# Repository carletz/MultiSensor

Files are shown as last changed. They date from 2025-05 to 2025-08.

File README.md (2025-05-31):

# ESPHome 🧠 MultiSensor Board

This repository contains the full hardware and firmware implementation of a smart multisensor platform powered by ESP32-S3, designed for home and building automation environments.
The purpose of this sensor is to install it on the room ceiling and detect the data by transmitting it to MQTT server, and use the IR led for communication with equipment such as televisions, air conditioners and more.
The idea was to have a sensor that could be freed from the difficulty of running power cables and data cables. The use of ethernet cables and POE connection facilitates the entire distribution and guarantees the correct connection in case of Wi-Fi difficulties.
It is still possible to connect it with a USB-C port and a wireless network but it was not designed for that.

---
## 🔧 Features

- **ESP32-S3 microcontroller** with USB-C and GPIO breakout
- **Power-over-Ethernet (PoE)** with isolated DC-DC conversion (via TPS2376 + F0505S module)
- **W5500 Ethernet controller** with magnetics and RJ45 connector
- **Sensor suite includes:**
  - BME280 for temperature, humidity, pressure (I²C)
  - BH1750 light sensor (I²C)
  - SCD41 for CO₂, humidity, temperature (I²C)
  - HLK-LD2410C-P mmWave presence sensor (UART)
  - SFH4546 IR emitters
- **GPIOs for external modules**
- **3.3V and 5V power rails with LDO and flyback conversion**
- **Status LEDs and reset circuitry**
- **Designed in EasyEDA (3 schematic sheets)**

## 🖼️ Board Preview

Below is a 3D render of the custom MultiSensor PCB, including:
- ESP32-S3
- W5500 Ethernet with PoE
- Sensors (BME280, BH1750, SCD41, HLK-LD2410C-P)
- USB-C and GPIO headers

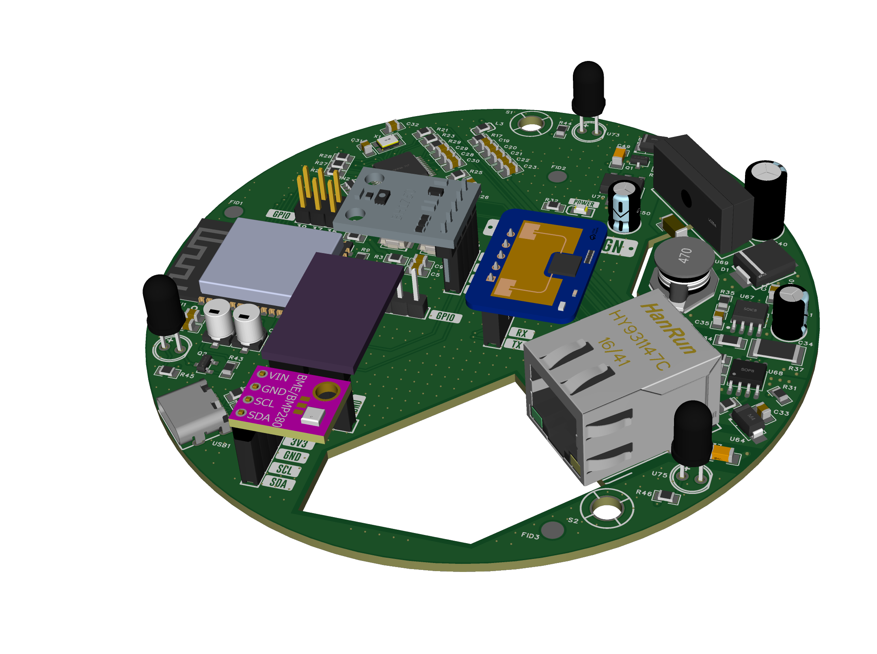
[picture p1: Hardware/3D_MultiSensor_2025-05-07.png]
3D Render of the MultiSensor Board


---
## 🎥 Construction Video

Watch the video (https://www.youtube.com/watch?v=1dLpgVjPY0A)

---
## 📡 Firmware

The board runs on **ESPHome**, fully integrated with:
- MQTT publishing (structured per sensor category)
- Web interface on Ethernet
- OTA update
- Diagnostics, presence, and environmental data

See Sensor.yaml for the complete ESPHome configuration.
Please consider that in this case, for the publication of the topics, the file is set having different floors and different rooms, the names are just an example.

## 📂 Folder Structure

- `Software` → ESPHome configuration
- `Hardware` → Complete hardware schematic (3 pages) and PCB design
- `3D design` → **Under developement** 3D model for 3D printed case
- `LICENSE` → MIT License

---
## 🧰 Getting Started

1. Flash `Sensor.yaml` using ESPHome Dashboard or CLI.
2. Connect the board to a PoE-enabled Ethernet switch or inject 5V via USB-C.
3. Open the web interface at the IP assigned via DHCP.
4. Integrate with Home Assistant or any MQTT broker at `192.168.1.XXX`.

---
## ⚠️ Disclaimer

This project is provided **for educational purposes only**.

The author(s) of this repository do **not take any responsibility** for:
- Incorrect use of the design or schematics
- Damage to equipment, persons, or property
- Installation in unsafe or non-compliant environments

Any implementation of this project in real-world systems should be done **under the responsibility of a qualified professional**, and in compliance with local regulations and safety standards.

By using this material, you acknowledge that it is offered **as-is, without warranty of any kind**, and you agree to use it **at your own risk**.

## 🌍 Language Note

Please note that some of the documentation and schematic files included in this project are written in **Italian**.

This is because the project was originally developed and documented for local use. I plan to translate all materials into **English** as time permits, to make the project more accessible to the international community.

If you need help understanding any specific part, feel free to open an issue or contact me — I'll be happy to help.

Grazie for your patience! 🇮🇹🙂

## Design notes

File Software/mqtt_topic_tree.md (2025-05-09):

# MQTT Topic Tree for ESPHome - Piano4 / Studio

This document outlines all MQTT topics published by the ESPHome node `sensore_piano4_studio`, located in the area `Piano4`, stanza `Studio`.

## 📡 MQTT Topics

```
Piano4/Studio/
├── Ambiente/
│   ├── Pressione
│   ├── Temperatura
│   └── Umidita
├── Aria/
│   ├── CO2
│   ├── Temperatura
│   └── Umidita
├── Diagnostica/
│   ├── Bluetooth
│   ├── Engineering Mode
│   ├── ESP_Reboot
│   ├── Esp temperatura
│   ├── IP
│   ├── DNS
│   ├── MAC
│   ├── Query
│   ├── Reboot
│   ├── Reset
│   ├── Uptime
│   └── Versione
├── IR/
│   └── Accendi_TV
├── Luce/
│   └── Lux
├── Presenza/
│   ├── Detection distance
│   ├── Light
│   ├── Move energy
│   ├── Moving distance
│   ├── Moving_target
│   ├── Out_pin
│   ├── Presence
│   ├── Still energy
│   ├── Still distance
│   ├── Still_target
│   ├── G0/
│   │   ├── Move_Energy
│   │   ├── Still_Energy
│   │   ├── Move Threshold
│   │   └── Still Threshold
│   ├── G1/ ... G8/
│   │   (identico a G0 per ogni gruppo)
│   └── Parametri/
│       ├── Baud Rate
│       ├── Distance Resolution
│       ├── G0 → G8/
│       │   ├── Move Threshold
│       │   └── Still Threshold
│       ├── Light Function
│       ├── Light Threshold
│       ├── Max Move Distance
│       ├── Max Still Distance
│       ├── Out Pin Level
│       └── Timeout
```

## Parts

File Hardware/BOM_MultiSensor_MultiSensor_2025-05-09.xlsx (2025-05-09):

No. | Quantity | Comment | Designator | Footprint | Value | Manufacturer Part | Manufacturer | Supplier Part | Supplier | LCSC Stock | LCSC Price | Primary Category | Secondary Category | Pin Count | JLCPCB Stock | JLCPCB Price | 3D Model Title | Device | Name | Unique ID | Convert to PCB | Add into BOM | Symbol | Layer | Mounting Style
1 | 2 | TS-1088-AR02016 | ((BOOT)),((RESET)) | SW-SMD_L3.9-W3.0-P4.45 |  | TS-1088-AR02016 | XUNPU(讯普) | C720477 | LCSC |  |  | Switches | Tactile Switches | 2 |  |  | SW-SMD_L3.9-W2.9-H2.0-LS4.8 | TS-1088-AR02016 | TS-1088-AR02016 | gge95,gge98 |  | yes |  | T | Brick nogging
2 | 1 | XL-2012SURC | ((POWER)) | LED0805-R-RD |  | XL-2012SURC | XINGLIGHT(成兴光) | C965812 | LCSC |  |  | Optoelectronics | LED Indication - Discrete | 2 |  |  | LED0805-RD | XL-2012SURC | XL-2012SURC | gge156_10 |  | yes |  | T
3 | 2 | 10uF | C1,C11 | C0805 | 10uF | CL21A106KOQNNNE | SAMSUNG(三星) | C1713 | LCSC |  |  | Capacitors | Multilayer Ceramic Capacitors MLCC - SMD/SMT | 2 |  |  | C0805_L2.0-W1.3-H1.3 | CL21A106KOQNNNE | 10uF | gge199,gge200 |  | yes |  | T
4 | 2 | 10uF | C2,C3 | CAP-SMD_BD4.0-L4.3-W4.3-LS5.1-FD | 10uF | VE-100M1ATR-0405 | lelon(立隆) | C249449 | LCSC |  |  | Capacitors | Aluminum Electrolytic Capacitors - SMD | 2 |  |  | CAP-SMD_BD4.0-L4.3-W4.3-LS5.1-FD | VE-100M1ATR-0405 | 10uF | gge137_1,gge138_1 |  | yes |  | T
5 | 10 | 100nF | C4,C6,C7,C12,C13,C14,C15,C21,C26,C32 | C0805 | 100nF | CL21B104KCFNNNE | SAMSUNG(三星) | C28233 | LCSC |  |  | Capacitors | Multilayer Ceramic Capacitors MLCC - SMD/SMT | 2 |  |  | C0805_L2.0-W1.3-H1.3 | CL21B104KCFNNNE | 100nF | gge211,gge212,gge213,gge213_1,gge214,gge214_1,gge215,gge216,gge217,gge218 |  | yes |  | T
6 | 1 | 1uF | C5 | C0805 | 1uF | HHV0805R7105K101NSLJ | Chinocera(华瓷) | C22367837 | LCSC |  |  | Capacitors | Multilayer Ceramic Capacitors MLCC - SMD/SMT | 2 |  |  | C0805_L2.0-W1.3-H1.3 | HHV0805R7105K101NSLJ | 1uF | gge251 |  | yes |  | T
7 | 1 | 10uF | C8 | C1206 | 10uF | CL31A106KBHNNNE | SAMSUNG(三星) | C13585 | LCSC |  |  | Capacitors | Multilayer Ceramic Capacitors MLCC - SMD/SMT | 2 |  |  | C1206_L3.2-W1.6-H1.3 | CL31A106KBHNNNE | 10uF | gge48_1 |  | yes |  | T
8 | 1 | 10uF | C9 | CAP-TH_BD5.0-P2.00-D0.8-FD | 10uF | GR106M050D11RR0VK2FP0 | CX(承兴) | C78759 | LCSC |  |  | Capacitors | Aluminum Electrolytic Capacitors - Leaded | 2 |  |  | CAP-TH_D5.0×H7.0×P2.0 | GR106M050D11RR0VK2FP0 | 10uF | gge120_1 |  | yes |  | T
9 | 2 | 6.8nF | C10,C18 | C0805 | 6.8nF | 0805B682K500NT | FH(风华) | C1755 | LCSC |  |  | Capacitors | Multilayer Ceramic Capacitors MLCC - SMD/SMT | 2 |  |  | C0805_L2.0-W1.3-H1.3 | 0805B682K500NT | 6.8nF | gge233,gge234 |  | yes |  | T
10 | 2 | 10nF | C16,C20 | C0805 | 10nF | FV21X103K102ECG | PSA(信昌电陶) | C565682 | LCSC |  |  | Capacitors | Multilayer Ceramic Capacitors MLCC - SMD/SMT | 2 |  |  | C0805_L2.0-W1.3-H1.3 | FV21X103K102ECG | 10nF | gge206,gge207 |  | yes |  | T
11 | 1 | 22nF | C17 | C0805 | 22nF | CC0805KRX7R9BB223 | YAGEO(国巨) | C107147 | LCSC |  |  | Capacitors | Multilayer Ceramic Capacitors MLCC - SMD/SMT | 2 |  |  | C0805_L2.0-W1.3-H1.3 | CC0805KRX7R9BB223 | 22nF | gge255 |  | yes |  | T
12 | 1 | 4.7uF | C19 | C0805 | 4.7uF | CC0805KKX7R5BB475 | YAGEO(国巨) | C520073 | LCSC |  |  | Capacitors | Multilayer Ceramic Capacitors MLCC - SMD/SMT | 2 |  |  | C0805_L2.0-W1.3-H1.3 | CC0805KKX7R5BB475 | 4.7uF | gge228 |  | yes |  | T
13 | 1 | 1nF | C22 | C1206 | 1nF | HHV1206R7102K202NSLJ | Chinocera | C5186823 | LCSC |  |  | Capacitors | Multilayer Ceramic Capacitors MLCC - SMD/SMT | 2 |  |  | C1206_L3.2-W1.6-H1.3 | CC1206KKX7RDBB102 | 1nF | gge275 |  | yes |  | T
14 | 2 | 20pF | C23,C24 | C0805 | 20pF | TCC0805COG200J500BT | CCTC(三环) | C309037 | LCSC |  |  | Capacitors | Multilayer Ceramic Capacitors MLCC - SMD/SMT | 2 |  |  | C0805_L2.0-W1.3-H1.3 | TCC0805COG200J500BT | 20pF | gge229,gge230 |  | yes |  | T
15 | 2 | 1nF | C25,C30 | C1808 | 1nF | 1808B102K302NT | FH(风华) | C967608 | LCSC |  |  | Capacitors | Multilayer Ceramic Capacitors MLCC - SMD/SMT | 2 |  |  | C1808_L4.5-W2.0-H2.0 | 1808B102K302NT | 1nF | gge307,gge308 |  | yes |  | T
16 | 1 | 15uF | C27 | CAP-TH_BD5.0-P2.00-D0.8-FD | 15uF | LKMB1102A150MF | Ymin(永铭) | C443117 | LCSC |  |  | Capacitors | Aluminum Electrolytic Capacitors - Leaded | 2 |  |  | CAP-TH_D5.0×H7.0×P2.0 | LKMB1102A150MF | 15uF | gge269 |  | yes |  | T
17 | 1 | 12pF | C28 | C0805 | 12pF | 0805CG120J500NT | FH(风华) | C1792 | LCSC |  |  | Capacitors | Multilayer Ceramic Capacitors MLCC - SMD/SMT | 2 |  |  | C0805_L2.0-W1.3-H1.3 | 0805CG120J500NT_C1792 | 12pF | gge277 |  | yes |  | T
18 | 1 | 470uF | C29 | CAP-TH_BD6.3-P2.50-D1.0-FD | 470uF | NXB10V470M6.3*11 LO | SAMYOUNG(韩国三莹) | C371106 | LCSC |  |  | Capacitors | Aluminum Electrolytic Capacitors - Leaded | 2 |  |  | CAP-TH_BD6.3-P2.50-D1.0-FD | NXB10V470M6.3*11 LO | 470uF | gge280 |  | yes |  | T
19 | 1 | 22uF | C31 | C0805 | 22uF | CL21A226MQQNNNE | SAMSUNG(三星) | C5674 | LCSC |  |  | Capacitors | Multilayer Ceramic Capacitors MLCC - SMD/SMT | 2 |  |  | C0805_L2.0-W1.3-H1.3 | CL21A226MQQNNNE | 22uF | gge284 |  | yes |  | T
20 | 1 | SS510C | D1 | SMC_L7.1-W6.2-LS8.1-R-RD |  | SS510C | FUXINSEMI | C908242 | LCSC |  |  | Diodes | Schottky Diodes | 2 |  |  | SMC_L7.1-W6.2-LS8.1-RD1 | SS510C | SS510C | gge272 |  | yes |  | T
21 | 1 | SMBJ6.0A | D2 | SMB_L4.6-W3.6-LS5.3-RD |  | SMBJ6.0A | Littelfuse(美国力特) | C83270 | LCSC |  |  | Circuit Protection | ESD and Surge Protection (TVS/ESD) | 2 |  |  | SMB_L4.6-W3.6-LS5.3-R-RD | SMBJ6.0A_C83270 | SMBJ6.0A | gge285 |  | yes |  | T
22 | 1 | 1N5819 | D3 | SMA_L4.4-W2.6-LS5.0-RD |  | 1N5819 | KEXIN(科信) | C437199 | LCSC |  |  | Diodes | Schottky Diodes | 2 |  |  | SMA_L4.4-W2.6-LS5.0-RD | 1N5819_C437199 | 1N5819 | gge261 |  | yes |  | T
23 | 3 | Fiducial | FID1,FID2,FID3 | Fiducial10-30 |  |  | N/A |  |  |  |  |  |  | 1 |  |  |  | Fiducial | Fiducial | gge299,gge300,gge301 |  | yes |  | T
24 | 1 | HDR-M_2.54_2x3 | H1 | HDR-TH_6P-P2.54-V-R2-C3-S2.54_A2541WV-2X3P |  |  |  |  |  |  |  | Connectors | Pin Headers | 6 |  |  | HDR2.54-M-LI-2x3P | HDR-M_2.54_2x3 |  | gge260 |  | yes |  | T
25 | 4 | 2.54-1*4P母 | H2,H6,H7,H8 | HDR-TH_4P-P2.54-V-F |  | 2.54-1*4P母 | BOOMELE(博穆精密) | C2718488 | LCSC |  |  | Connectors | Female Headers | 4 |  |  | HDR-TH_4P-P2.54-V-F-2,HDR-TH_4P-P2.54-V-F-3_WJ254 | 2.54-1*4P母 | 2.54-1*4P母 | gge302,gge303,gge303_1,gge304 |  | yes |  | T
26 | 1 | 2.54-1*5P母 | H5 | HDR-TH_5P-P2.54-V-F |  | 2.54-1*5P母 | BOOMELE(博穆精密) | C50950 | LCSC |  |  | Connectors | Female Headers | 5 |  |  | HDR-TH_5P-P2.54-V-F-B | HDR-F_2.54_1x5P |  | gge305 |  | yes |  | T
27 | 1 | HCB2012KF-121T50 | L1 | L0805 |  | HCB2012KF-121T50 | TAI-TECH(台庆) | C304323 | LCSC |  |  | Filters | Ferrite Beads | 2 |  |  | R0805_L2.0-W1.3-H0.6 | HCB2012KF-121T50 | HCB2012KF-121T50 | gge241 |  | yes |  | T
28 | 1 | 33uH | L2 | IND-SMD_L12.9-W9.8 | 33uH | SMSD0804-330MT | SXN(顺翔诺) | C286357 | LCSC |  |  | Inductors, Coils, Chokes | Power Inductors | 2 |  |  | IND-SMD_L12.9-W9.8-H5.2 | SMSD0804-330MT | 33uH | gge276 |  | yes |  | T
29 | 1 | WPM2015-3/TR | Q1 | SOT-23-3_L2.9-W1.3-P1.90-LS2.4-BR |  | WPM2015-3/TR | KUU | C6562215 | LCSC |  |  | Transistors/Thyristors | MOSFETs | 3 |  |  | SOT-23-3P_L2.9-W1.3-H1.0-LS2.4-P0.95 | WPM2015-3/TR_C6562215 | WPM2015-3/TR | gge262 |  | yes |  | T
30 | 1 | BSS138BK | Q2 | SOT-23-3_L2.9-W1.3-P1.90-LS2.4-BR |  | BSS138BK | ElecSuper(静芯微) | C5224267 | LCSC |  |  | Transistors/Thyristors | MOSFETs | 3 |  |  | SOT-23-3P_L2.9-W1.3-H1.0-LS2.4-P0.95 | BSS138BK | BSS138BK | gge292 |  | yes |  | T
31 | 3 | 10Ω | R1,R2,R13 | R0805_NEW | 10Ω | 0805W8F100JT5E | UNI-ROYAL(厚声) | C17415 | LCSC |  |  | Resistors | Chip Resistor - Surface Mount | 2 |  |  | R0805_L2.0-W1.3-H0.6 | 0805W8F100JT5E | 10Ω | gge239,gge249,gge250 |  | yes |  | T
32 | 13 | 10kΩ | R3,R4,R5,R6,R7,R8,R9,R11,R21,R22,R23,R24,R33 | R0805 | 10kΩ | RC0805FR-7W10KL | YAGEO(国巨) | C17414 | LCSC |  |  | Resistors | Chip Resistor - Surface Mount | 2 |  |  | R0805_L2.0-W1.3-H0.6 | RC0805FR-7W10KL | 10kΩ | gge202,gge202_1,gge203,gge204,gge205,gge220,gge221,gge222,gge223,gge224,gge224_1,gge225,gge226 |  | yes |  | T
33 | 2 | 2kΩ | R10,R37 | R0805 | 2kΩ | 0805W8J0202T5E | UNI-ROYAL(厚声) | C1359 | LCSC |  |  | Resistors | Chip Resistor - Surface Mount | 2 |  |  | R0805_L2.0-W1.3-H0.6 | 0805W8J0202T5E | 2kΩ | gge253_1,gge253_2 |  | yes |  | T
34 | 1 | 0Ω | R12 | R0805 | 0Ω | 0805W8F0000T5E | UNI-ROYAL(厚声) | C17477 | LCSC |  |  | Resistors | Chip Resistor - Surface Mount | 2 |  |  | R0805_L2.0-W1.3-H0.6 | 0805W8F0000T5E_C17477 | 0Ω | gge240 |  | yes |  | T
35 | 2 | 49.9Ω | R14,R15 | R0805 | 49.9Ω | 0805W8F499JT5E | UNI-ROYAL(厚声) | C17720 | LCSC |  |  | Resistors | Chip Resistor - Surface Mount | 2 |  |  | R0805_L2.0-W1.3-H0.6 | 0805W8F499JT5E | 49.9Ω | gge237,gge238 |  | yes |  | T
36 | 2 | 82Ω | R16,R17 | R0805 | 82Ω | RC0805FR-0782RL | YAGEO(国巨) | C141699 | LCSC |  |  | Resistors | Chip Resistor - Surface Mount | 2 |  |  | R0805_L2.0-W1.3-H0.6 | RC0805FR-0782RL | 82Ω | gge231,gge232 |  | yes |  | T
37 | 2 | 510Ω | R18,R19 | R0805 | 510Ω | FRC0805J511 TS | FOJAN(富捷) | C2907333 | LCSC |  |  | Resistors | Chip Resistor - Surface Mount | 2 |  |  | R0805_L2.0-W1.3-H0.6 | FRC0805J511 TS | 510Ω | gge235,gge236 |  | yes |  | T
38 | 1 | 12.4kΩ | R20 | R0805 | 12.4kΩ | 0805W8F1242T5E | UNI-ROYAL(厚声) | C30908 | LCSC |  |  | Resistors | Chip Resistor - Surface Mount | 2 |  |  | R0805_L2.0-W1.3-H0.6 | 0805W8F1242T5E | 12.4kΩ | gge243 |  | yes |  | T
39 | 1 | 4.7Ω | R25 | R0805 | 4.7Ω | FRC0805F4R70TS | FOJAN(富捷) | C2907327 | LCSC |  |  | Resistors | Chip Resistor - Surface Mount | 2 |  |  | R0805_L2.0-W1.3-H0.6 | FRC0805F4R70TS | 4.7Ω | gge271 |  | yes |  | T
40 | 1 | 4.7kΩ | R26 | R2512 | 4.7kΩ | FRC2512J472 TS | FOJAN | C2907583 | LCSC |  |  | Resistors | Chip Resistor - Surface Mount | 2 |  |  | R2512_L6.3-W3.2-H0.6 | 25121WF4701T4E | 4.7kΩ | gge274 |  | yes |  | T
41 | 1 | 56.2kΩ | R27 | R0805 | 56.2kΩ | FRC0805F5622TS | FOJAN(富捷) | C2933471 | LCSC |  |  | Resistors | Chip Resistor - Surface Mount | 2 |  |  | R0805_L2.0-W1.3-H0.6 | FRC0805F5622TS | 56.2kΩ | gge278 |  | yes |  | T
42 | 1 | 180kΩ | R28 | R0805 | 180kΩ | FRC0805F1803TS | FOJAN(富捷) | C2907230 | LCSC |  |  | Resistors | Chip Resistor - Surface Mount | 2 |  |  | R0805_L2.0-W1.3-H0.6 | FRC0805F1271TS | 180kΩ | gge266 |  | yes |  | T
43 | 1 | 30mΩ | R29 | R1206 | 30mΩ | PA1206FRF470R03L | YAGEO(国巨) | C728293 | LCSC |  |  | Resistors | Chip Resistor - Surface Mount | 2 |  |  | R1206_L3.2-W1.6-H0.6 | PA1206FRF470R03L | 30mΩ | gge270 |  | yes |  | T
44 | 1 | 130kΩ | R30 | R0805 | 130kΩ | FRC0805F1303TS | FOJAN | C2933305 | LCSC |  |  | Resistors | Chip Resistor - Surface Mount | 2 |  |  | R0805_L2.0-W1.3-H0.6 | RC0805FR-7W10KL | 130kΩ | gge202_2 |  | yes |  | T
45 | 1 | 10.5kΩ | R31 | R0805 | 10.5kΩ | FRC0805F1052TS | FOJAN | C2960821 | LCSC |  |  | Resistors | Chip Resistor - Surface Mount | 2 |  |  | R0805_L2.0-W1.3-H0.6 | FRC0805F5622TS | 10.5kΩ | gge279 |  | yes |  | T
46 | 1 | 4.42kΩ | R32 | R0805 | 4.42kΩ | FRC0805F4421TS | FOJAN(富捷) | C2960870 | LCSC |  |  | Resistors | Chip Resistor - Surface Mount | 2 |  |  | R0805_L2.0-W1.3-H0.6 | FRC0805F6652TS | 4.42kΩ | gge267 |  | yes |  | T
47 | 3 | 24Ω | R34,R35,R36 | R0805 | 24Ω | 0805W8F240JT5E | UNI-ROYAL(厚声) | C17576 | LCSC |  |  | Resistors | Chip Resistor - Surface Mount | 2 |  |  | R0805_L2.0-W1.3-H0.6 | 0805W8F240JT5E | 24Ω | gge293,gge294,gge295 |  | yes |  | T
48 | 1 | HY931147C | RJ1 | RJ45-TH_HY931147C |  | HY931147C | HANRUN(汉仁) | C91754 | LCSC |  |  | Connectors | Ethernet Connectors / Modular Connectors (RJ45 RJ11) | 16 |  |  | RJ45-TH_HY931147C | HY931147C | HY931147C | gge263 |  | yes |  | T | -
49 | 2 | 10kΩ | RN1,RN2 | RES-ARRAY-SMD_0603-8P-L3.2-W1.6-BL | 10kΩ | 4D03WGJ0103T5E | UNI-ROYAL(厚声) | C29718 | LCSC |  |  | Resistors | Resistor Networks, Arrays | 8 |  |  | R0603-8P_L3.2-W1.6-H0.6 | 4D03WGJ0103T5E | 10kΩ | gge208,gge210 |  | yes |  | T
50 | 1 | HLK-LD2410C-P | SM1 | SENSOR-TH_HLK-LD2410C-P |  | HLK-LD2410C-P | HI-LINK(海凌科) | C19723500 | LCSC |  |  | Sensors | Sensor Modules | 0 |  |  | SENSOR-TH_HLK-LD2410C-P | HLK-LD2410C-P | HLK-LD2410C-P | gge288 |  | yes |  | T
51 | 1 | 2.4GHz | U1 | WIRELM-SMD_ESP32-S3-WROOM-1 | 2.4GHz | ESP32-S3-WROOM-1-N8R2 | ESPRESSIF(乐鑫) | C2913204 | LCSC |  |  | IoT/Communication Modules | WiFi Modules | 49 |  |  | ESP32-S3-WROOM-1-N16R2 | ESP32-S3-WROOM-1-N8R2 | 2.4GHz | gge102 |  | yes |  | T
52 | 1 | BL1117-33CX | U2 | SOT-223-4_L6.5-W3.5-P2.30-LS7.0-BR |  | BL1117-33CX | BL(上海贝岭) | C5400 | LCSC |  |  | Power Management (PMIC) | Voltage Regulators - Linear, Low Drop Out (LDO) Regulators | 4 |  |  | SOT-223-4P_L6.5-W3.5-H1.6-LS7.0-P2.30 | BL1117-33CX | BL1117-33CX | gge46_1 |  | yes |  | T
53 | 1 | W5500 | U3 | LQFP-48_L7.0-W7.0-P0.50-LS9.0-BL |  | W5500 | WIZNET | C32843 | LCSC |  |  | Interface | Ethernet Controllers | 48 |  |  | LQFP-48_L7.0-W7.0-H1.4-LS9.0-P0.50 | W5500 | W5500 | gge86 |  | yes |  | T
54 | 1 | F0505S-2WR2 | U4 | PWRM-TH_FXXXXS-1WR2 |  | F0505S-2WR2 | DEXU(德旭电子) | C909777 | LCSC |  |  | Power Modules | Isolated Power Modules | 4 |  |  | PWRM-TH_FXXXXS-1WR2 | F0505S-2WR2 | F0505S-2WR2 | gge281 |  | yes |  | T
55 | 1 | 24.9kΩ | U5 | R0805 | 24.9kΩ | FRC0805F2492TS | FOJAN(富捷) | C2930185 | LCSC |  |  | Resistors | Chip Resistor - Surface Mount | 2 |  |  | R0805_L2.0-W1.3-H0.6 | FRC0805F2492TS | 24.9kΩ | gge265 |  | yes |  | T
56 | 1 | SMAJ58A | U6 | SMA_L4.3-W2.7-LS5.0-RD |  | SMAJ58A | GOODWORK(固得沃克) | C2980408 | LCSC |  |  | Circuit Protection | ESD and Surge Protection (TVS/ESD) | 2 |  |  | SMA_L4.3-W2.7-LS5.0-RD | SMAJ58A_C2980408 | SMAJ58A | gge264 |  | yes |  | T
57 | 1 | TPS2376DDAR-H | U7 | SO-8_L4.9-W3.9-P1.27-LS6.0-BL-EP |  | TPS2376DDAR-H | TI(德州仪器) | C544899 | LCSC |  |  | Power Management (PMIC) | Power Over Ethernet (PoE) Controllers | 9 |  |  | SO-8_L4.9-W3.9-H1.5-LS5.9-P1.27 | TPS2376DDAR-H | TPS2376DDAR-H | gge273 |  | yes |  | T
58 | 1 | TX4138 | U8 | SOIC-8_L4.9-W3.9-P1.27-LS6.0-BL-EP |  | TX4138 | XDS(芯鼎盛) | C329267 | LCSC |  |  | Power Management (PMIC) | DC-DC Converters | 9 |  |  | SOIC-8_L4.9-W3.9-H1.7-LS6.0-P1.27 | TX4138 | TX4138 | gge268 |  | yes |  | T
59 | 1 | BME280 | U9 | BME280 |  |  |  |  |  |  |  |  |  | 0 |  |  | Sensor BME280 | BME280 |  | gge286 |  | yes |  | T
60 | 3 | SFH 4546 | U11,U12,U13 | LED-TH_BD5.6-P2.54-FD |  | SFH 4546 | OSRAM(欧司朗) | C2900373 | LCSC |  |  | Optoelectronics | Infrared LED Emitters | 2 |  |  | LED-TH_BD5.6-P2.54-L5.6-H8.6-FD | SFH 4546 | SFH 4546 | gge289,gge290,gge291 |  | yes |  | T
61 | 1 | BH1750 | U14 | BH1750 |  |  |  |  |  |  |  |  |  | 0 |  |  | BH1750 | BH1750 |  | gge306 |  | yes |  | T
62 | 1 | SCD41 | U15 | SCD40/SCD41 MODULE |  |  |  |  |  |  |  | Sensores |  | 0 |  |  | scd40 v7 | SCD41 |  | gge297 |  | yes |  | T
63 | 1 | TYPE-C 16PIN 2MD(073) | USB1 | USB-C-SMD_TYPE-C-6PIN-2MD-073 |  | TYPE-C 16PIN 2MD(073) | SHOU HAN(首韩) | C2765186 | LCSC |  |  | Connectors | USB Connectors | 16 |  |  | USB-C-SMD_TYPE-C-6PIN-2MD-073 | TYPE-C 16PIN 2MD(073) | TYPE-C 16PIN 2MD(073) | gge130_2 |  | yes |  | T | Horizontal attachment
64 | 1 | 25MHz | X1 | CRYSTAL-SMD_4P-L3.2-W2.5-BL | 25MHz | X322525MOB4SI | YXC(扬兴晶振) | C9006 | LCSC |  |  | Crystals, Oscillators, Resonators | Crystals | 4 |  |  | OSC-SMD_4P-L3.2-W2.5-H1.0 COPY | X322525MOB4SI | 25MHz | gge131_1 |  | yes |  | T

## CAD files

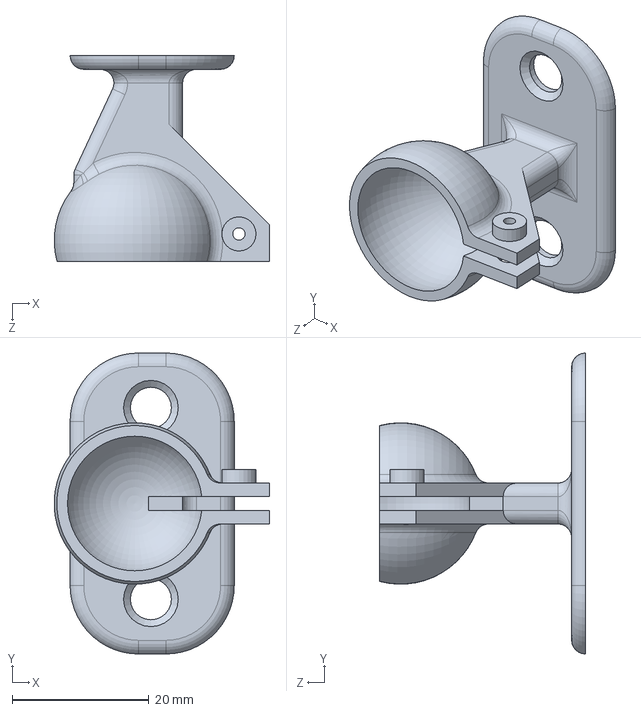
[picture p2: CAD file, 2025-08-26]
3D Design/Wall attach/PIEDE APPOGGIO.SLDPRT
31.5 x 44.0 x 30.1 mm

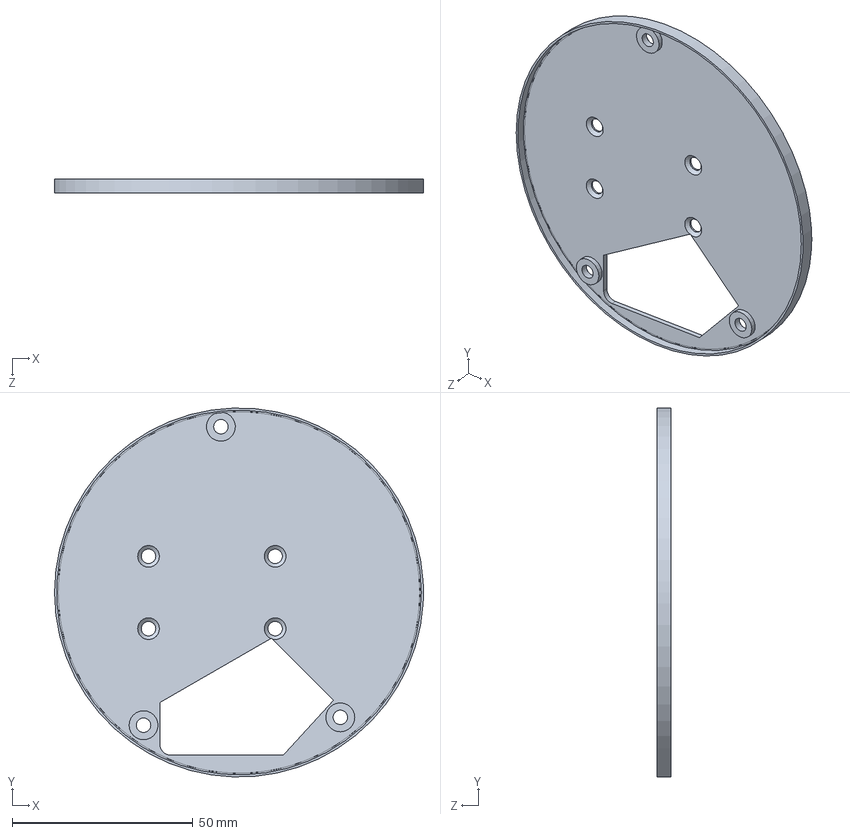
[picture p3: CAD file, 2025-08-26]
3D Design/Wall attach/BASE.SLDPRT
102.0 x 101.9 x 4.00 mm

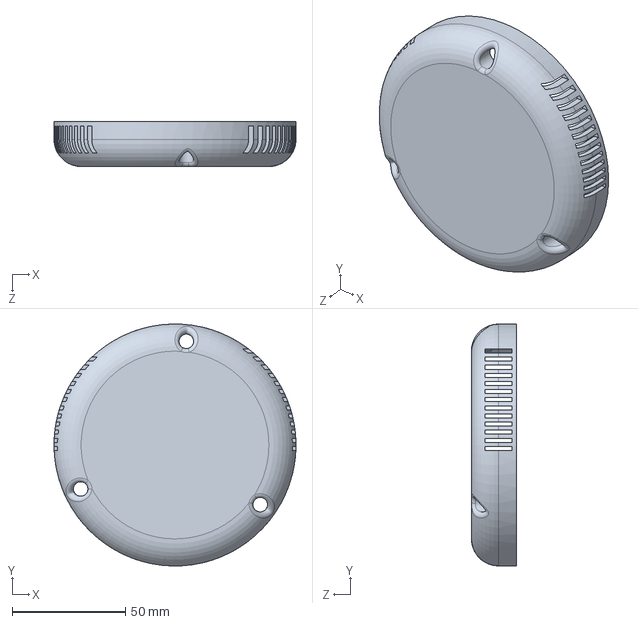
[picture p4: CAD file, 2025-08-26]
3D Design/Wall attach/COPERCHIO.SLDPRT
107.0 x 107.0 x 20.0 mm

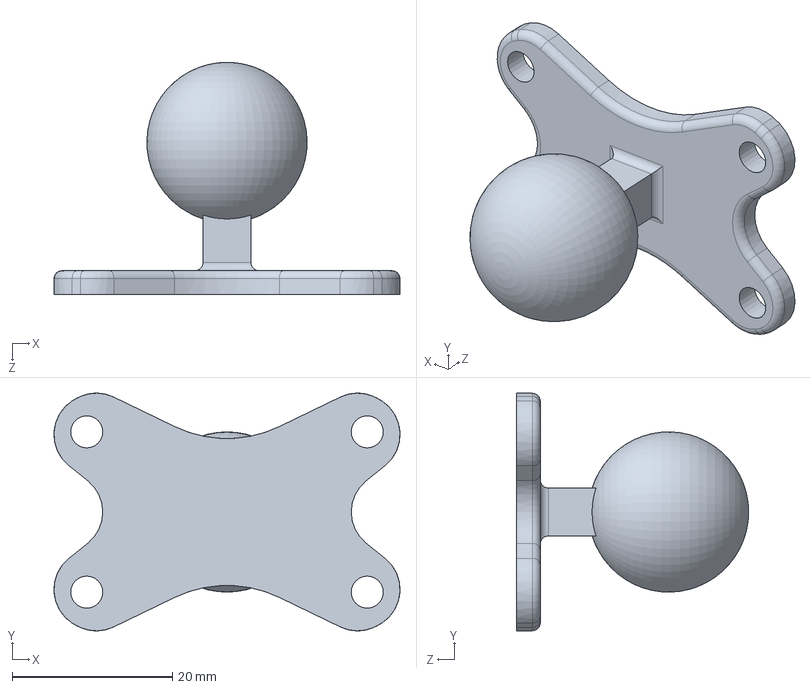
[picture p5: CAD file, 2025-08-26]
3D Design/Wall attach/SUPPORTO ATTACCATO.SLDPRT
43.2 x 29.7 x 29.0 mm

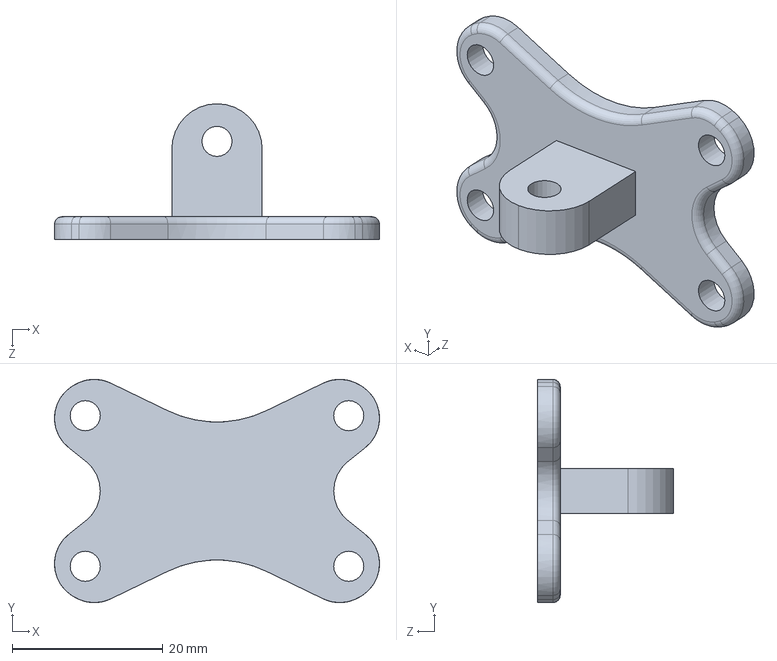
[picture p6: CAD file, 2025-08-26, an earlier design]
3D Design/Stand Alone/SUPPORTO ATTACCATO.SLDPRT
43.2 x 29.7 x 18.0 mm

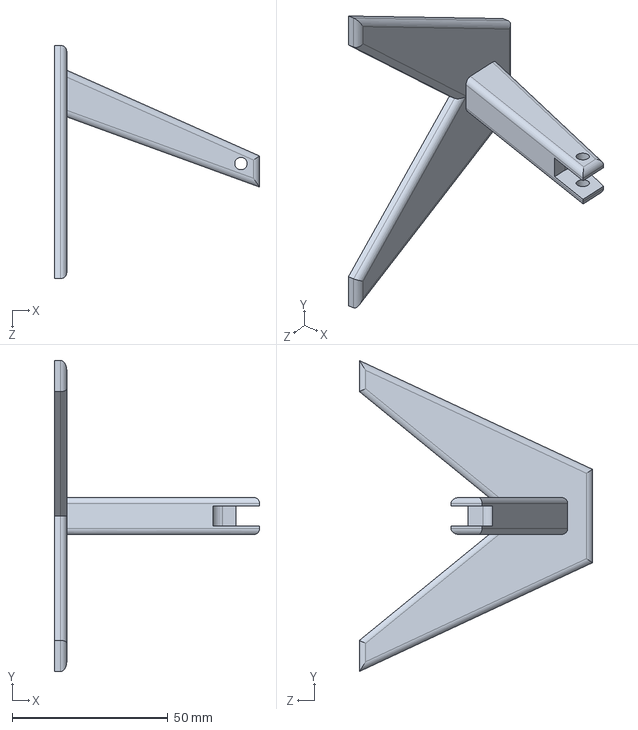
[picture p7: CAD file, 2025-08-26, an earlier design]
3D Design/Stand Alone/PIEDE APPOGGIO.SLDPRT
66.0 x 100.0 x 75.0 mm

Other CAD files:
3D Design/Stand Alone/PIEDE APPOGGIO.STL
3D Design/Stand Alone/SUPPORTO ATTACCATO.STL
3D Design/Wall attach/BASE.STL
3D Design/Wall attach/COPERCHIO.STL
3D Design/Wall attach/PIEDE APPOGGIO.STL
3D Design/Wall attach/SUPPORTO ATTACCATO.STL

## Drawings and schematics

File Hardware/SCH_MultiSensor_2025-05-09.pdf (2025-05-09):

# USB Microcontroller

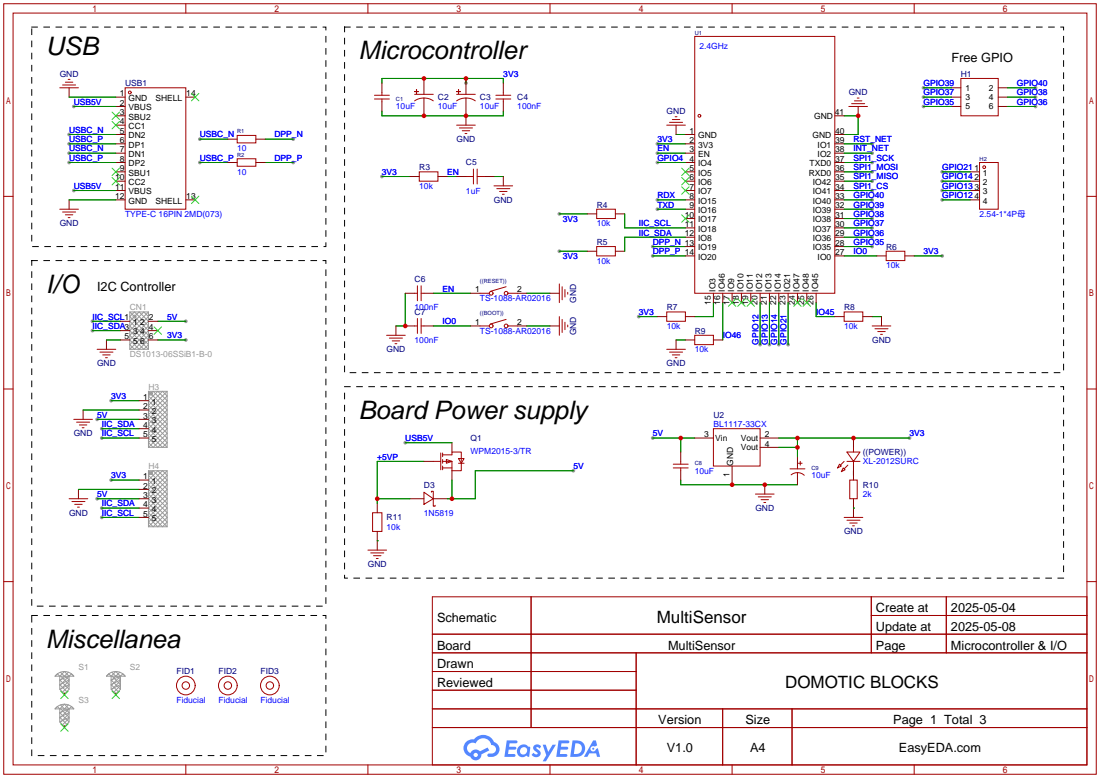
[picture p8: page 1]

Schematic | MultiSensor | Create at | 2025-05-04

Update at | 2025-05-08

Board | MultiSensor | Page | Microcontroller & I/O
Drawn | | DOMOTIC BLOCKS
Reviewed

Version | Size | Page 1 Total 3
V1.0 | A4 | EasyEDA.com

Ethernet POE | RX1_P

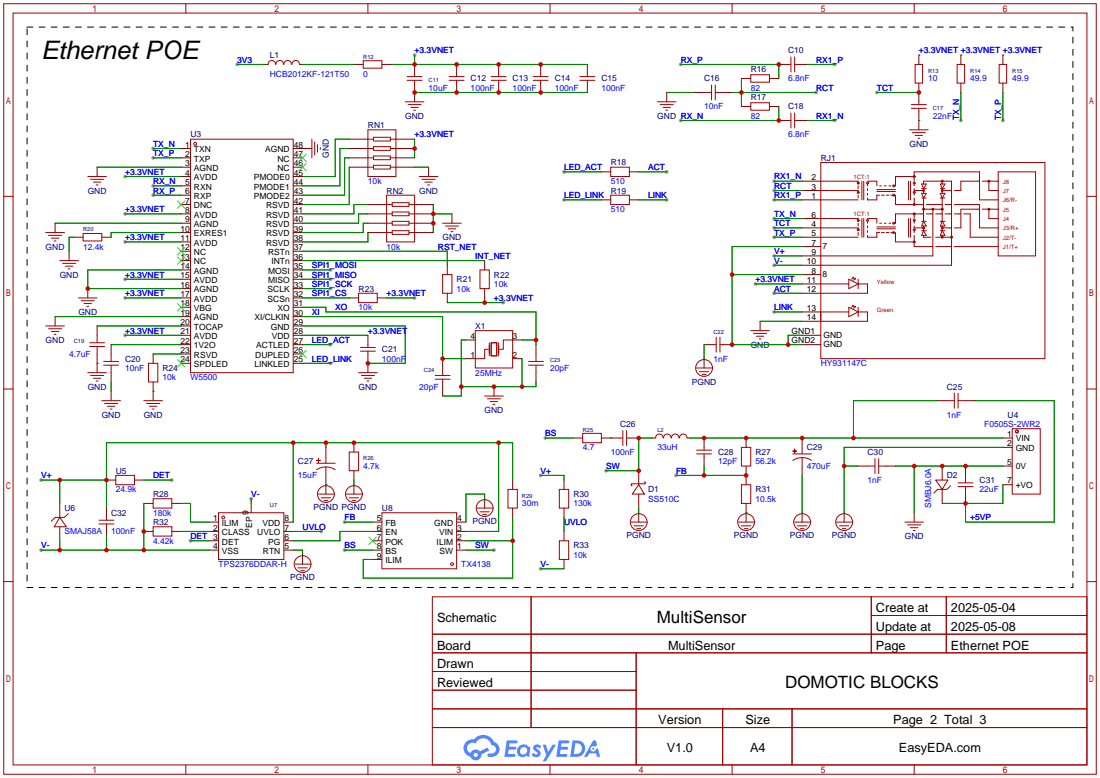
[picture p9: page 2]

Schematic | MultiSensor | Create at | 2025-05-04

Update at | 2025-05-08

Board | MultiSensor | Page | Ethernet POE
Drawn | | DOMOTIC BLOCKS
Reviewed

# GPIO4⁵V

# Sensors

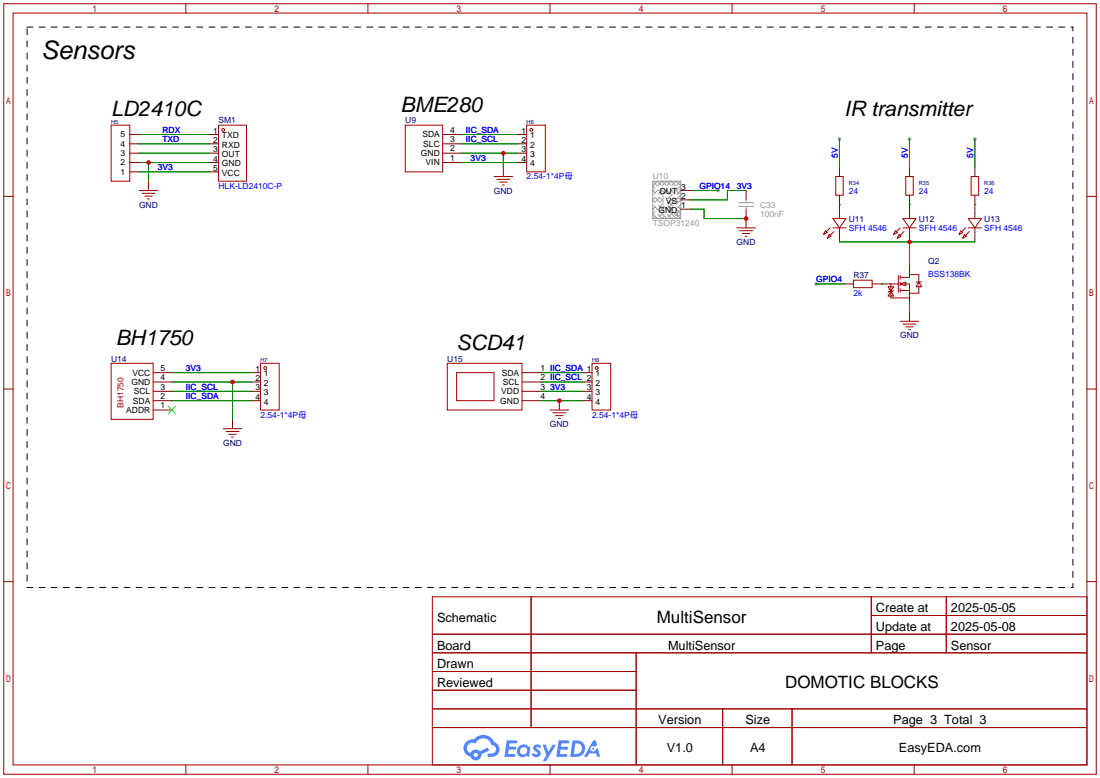
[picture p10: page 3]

Schematic | MultiSensor | Create at | 2025-05-05

Update at | 2025-05-08

Board | MultiSensor | Page | Sensor
Drawn | | DOMOTIC BLOCKS
Reviewed

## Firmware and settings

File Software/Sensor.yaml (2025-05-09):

esphome:
  name: "sensore_${area}_${stanza}".lower()  # es: sensore_piano4_studio
  friendly_name: "Sensore ${area} ${stanza}"  # es: Sensore Piano4 Studio
  platformio_options:
    board_build.flash_mode: dio

esp32:
  board: esp32-s3-devkitc-1
  framework:
    type: esp-idf

substitutions:
  area: "Piano4"          ## just for example, change at your use
  stanza: "Studio"        ## just for example, change at your use

ota:
  - platform: esphome
    password: ""

ethernet:
  type: W5500
  clk_pin: GPIO43
  mosi_pin: GPIO44
  miso_pin: GPIO42
  cs_pin: GPIO41
  interrupt_pin: GPIO2
  reset_pin: GPIO1
  manual_ip:
    static_ip: 192.168.1.69     ## just for example, change at your use
    gateway: 192.168.1.1
    subnet: 255.255.255.0

web_server:
  port: 80
  version: 3

logger:
  hardware_uart: USB_SERIAL_JTAG

mqtt:
  broker: 192.168.1.42          ## just for example, change at your use
  port: 1883

i2c:
  sda: GPIO08
  scl: GPIO18
  scan: true
  frequency: 400kHz
  id: bus_a

uart:
  tx_pin: GPIO16
  rx_pin: GPIO15
  baud_rate: 256000
  parity: NONE
  stop_bits: 1

ld2410:

binary_sensor:
  - platform: ld2410
    has_target:
      name: Presence
      id: bs_presence
      internal: false
      on_press:
        - mqtt.publish:
            topic: "${area}/${stanza}/Presenza/Presence"
            payload: "ON"
      on_release:
        - mqtt.publish:
            topic: "${area}/${stanza}/Presenza/Presence"
            payload: "OFF"
    has_moving_target:
      name: Moving Target
      id: bs_moving
      internal: false
      on_press:
        - mqtt.publish:
            topic: "${area}/${stanza}/Presenza/Moving_target"
            payload: "ON"
      on_release:
        - mqtt.publish:
            topic: "${area}/${stanza}/Presenza/Moving_target"
            payload: "OFF"
    has_still_target:
        name: Still Target
        id: bs_still
        internal: false
        on_press:
          - mqtt.publish:
              topic: "${area}/${stanza}/Presenza/Still_target"
              payload: "ON"
        on_release:
          - mqtt.publish:
              topic: "${area}/${stanza}/Presenza/Still_target"
              payload: "OFF"
    out_pin_presence_status:
      name: Out Pin Presence Status
      id: bs_out_pin
      internal: false
      on_press:
        - mqtt.publish:
            topic: "${area}/${stanza}/Presenza/Out_pin"
            payload: "ON"
      on_release:
        - mqtt.publish:
            topic: "${area}/${stanza}/Presenza/Out_pin"
            payload: "OFF"

sensor:
  - platform: bme280_i2c
    temperature:
      name: "BME280 Temperature"
      id: bme280_temp
      internal: true
      oversampling: 16x    
    pressure:
      name: "BME280 Pressure"
      id: bme280_press
      internal: true
    humidity:
      name: "BME280 Humidity"
      id: bme280_hum
      internal: true
    address: 0x76
    i2c_id: bus_a
    update_interval: 30s

  - platform: template
    name: "BME280 Temperatura"
    id: bme280_temp_template
    unit_of_measurement: "°C"
    lambda: |-
      return id(bme280_temp).state;
    update_interval: 30s
    state_topic: "${area}/${stanza}/Ambiente/Temperatura"
  - platform: template
    name: "BME280 Umidità"
    id: bme280_hum_template
    unit_of_measurement: "%"
    lambda: |-
      return id(bme280_hum).state;
    update_interval: 30s
    state_topic: "${area}/${stanza}/Ambiente/Umidita"
  - platform: template
    name: "BME280 Pressione"
    id: bme280_press_template
    unit_of_measurement: "hPa"
    lambda: |-
      return id(bme280_press).state;
    update_interval: 30s
    state_topic: "${area}/${stanza}/Ambiente/Pressione"

  - platform: bh1750
    name: "Luce BH1750"
    id: lux_sens
    internal: true
    address: 0x23
    i2c_id: bus_a
    update_interval: 30s
  - platform: template
    name: "Luce BH1750"
    id: lux_sens_template
    unit_of_measurement: "lx"
    lambda: |-
      return id(lux_sens).state;
    update_interval: 30s
    state_topic: "${area}/${stanza}/Luce/Lux"

  - platform: scd4x
    co2:
      name: "CO2 SCD41"
      id: scd41_co2
      internal: true
    temperature:
      name: "Temperatura SCD41"
      id: scd41_temp
      internal: true
    humidity:
      name: "Umidità SCD41"
      id: scd41_hum
      internal: true
    update_interval: 60s
    i2c_id: bus_a
  - platform: template
    name: "CO2 SCD41"
    id: scd41_co2_template
    unit_of_measurement: "ppm"
    lambda: |-
      return id(scd41_co2).state;
    state_topic: "${area}/${stanza}/Aria/CO2"
  - platform: template
    name: "Temperatura SCD41"
    id: scd41_temp_template
    unit_of_measurement: "°C"
    lambda: |-
      return id(scd41_temp).state;
    state_topic: "${area}/${stanza}/Aria/Temperatura"
  - platform: template
    name: "Umidità SCD41"
    id: scd41_hum_template
    unit_of_measurement: "%"
    lambda: |-
      return id(scd41_hum).state;
    state_topic: "${area}/${stanza}/Aria/Umidita"
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
